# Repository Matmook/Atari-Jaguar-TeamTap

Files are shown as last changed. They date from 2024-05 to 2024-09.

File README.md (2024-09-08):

# Atari-Jaguar-TeamTap

This is an attempt to recreate the Atari Jaguar TeamTap schematic.

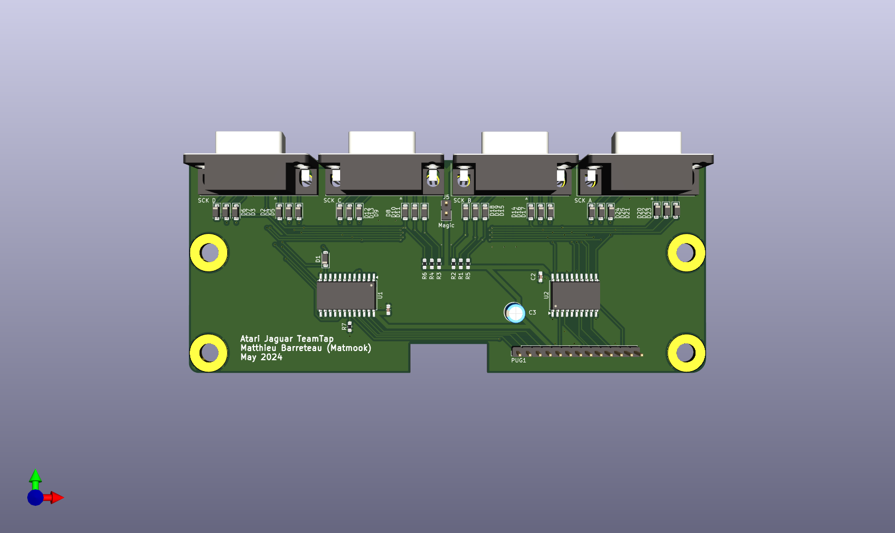
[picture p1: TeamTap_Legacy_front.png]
Front view

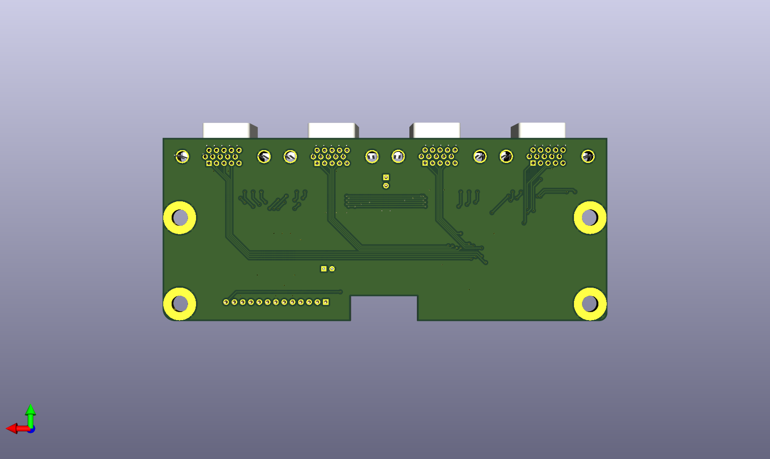
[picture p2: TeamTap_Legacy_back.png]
Back view


There is a catch on the original PCB: 
- the 5v from the Jaguar powers TeamTap's internal logic (74HC154 and 74HC244).
- pad's pin 7 is supposed to be used to power the pad's logic (74HC244).
- but all pads pin 7 are left floating in the TeamTam..
I guess that's some Atari magic => the pad's 74HC244 is fed by the other IOs, not VCC.
There is a "Magic" shunt on my pcb to test the pads behaviour when fed with 5v (as it should).

Matthieu Barreteau (Matmook) 2024

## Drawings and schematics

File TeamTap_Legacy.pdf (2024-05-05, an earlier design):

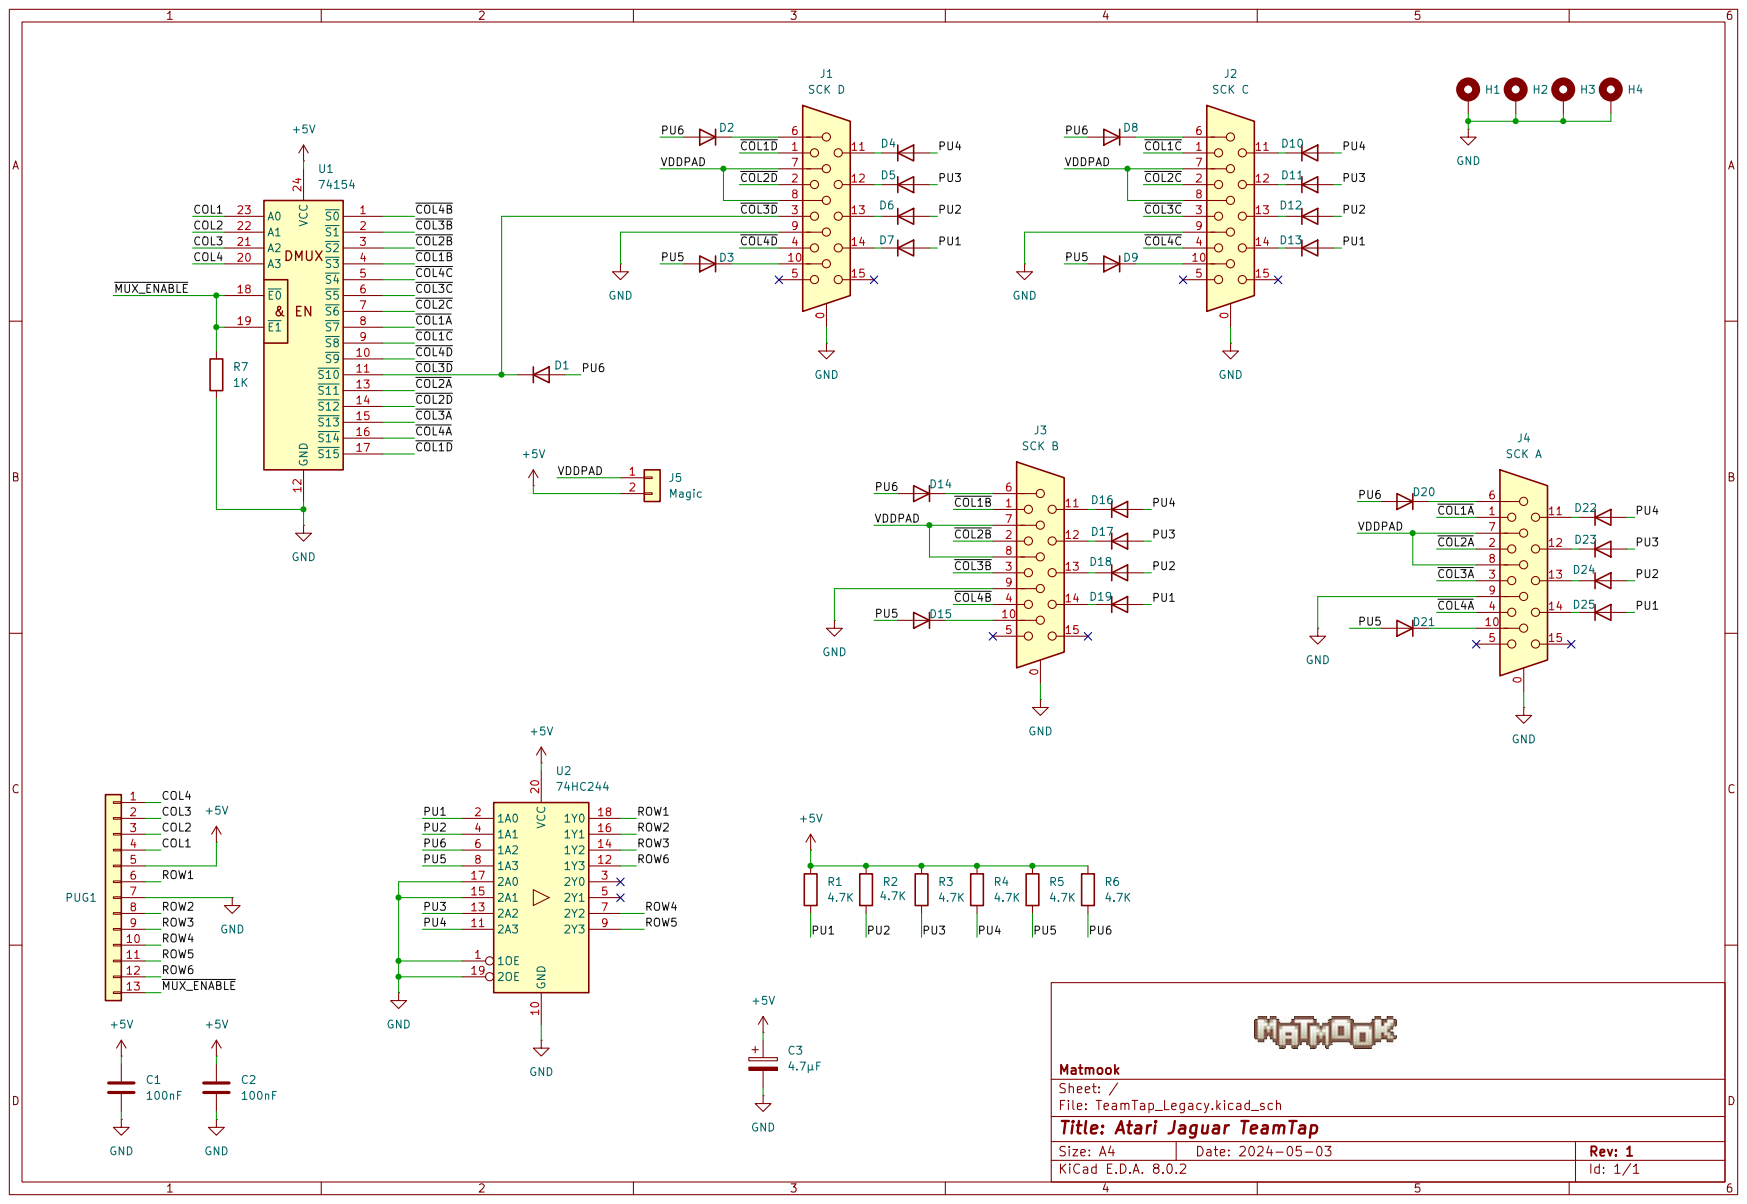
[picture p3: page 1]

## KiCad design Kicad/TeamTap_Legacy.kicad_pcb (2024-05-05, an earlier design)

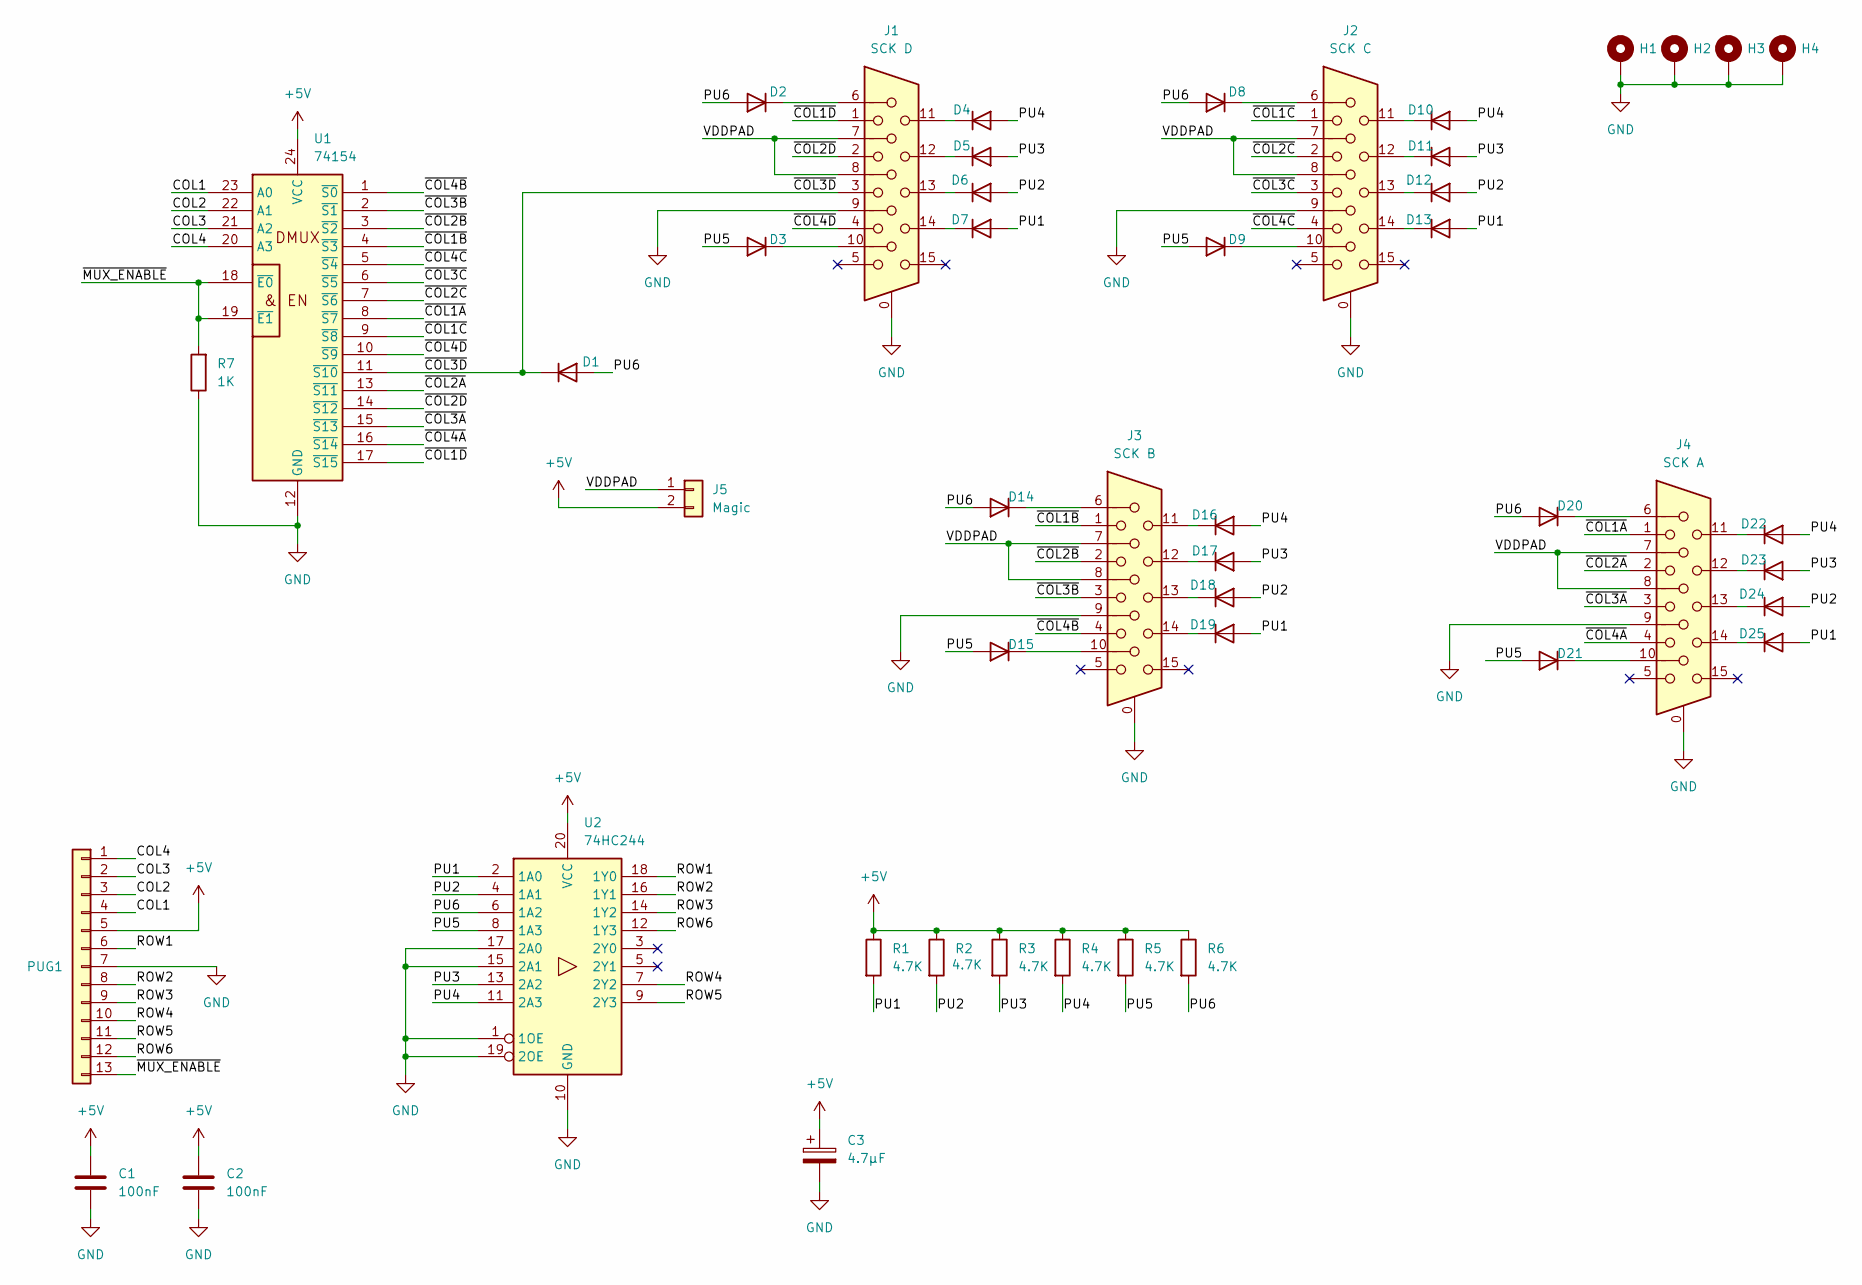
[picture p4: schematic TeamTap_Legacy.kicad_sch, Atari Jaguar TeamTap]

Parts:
C1, C2: 100nF; C_0603_1608Metric_Pad1.08x0.95mm_HandSolder
C3: 4.7µF; CP_Radial_D5.0mm_P2.50mm
D1, D2, D3, D4, D5, D6, D7, D8, D9, D10, D11, D12, D13, D14, D15, D16, D17, D18, D19, D20, D21, D22, D23, D24, D25: D; D_SOD-123
H1, H2, H3, H4: MountingHole_Pad; MountingHole_5mm_Pad_TopBottom
J1: SCK D; DSUB-15-HD_Male_Horizontal_P2.29x1.98mm_EdgePinOffset3.03mm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
J2: SCK C; DSUB-15-HD_Male_Horizontal_P2.29x1.98mm_EdgePinOffset3.03mm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
J3: SCK B; DSUB-15-HD_Male_Horizontal_P2.29x1.98mm_EdgePinOffset3.03mm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
J4: SCK A; DSUB-15-HD_Male_Horizontal_P2.29x1.98mm_EdgePinOffset3.03mm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
J5: Magic; PinHeader_1x02_P2.54mm_Vertical
PUG1: Conn_01x13; PinHeader_1x13_P2.54mm_Vertical
R1, R2, R3, R4, R5, R6: 4.7K; R_0603_1608Metric_Pad0.98x0.95mm_HandSolder
R7: 1K; R_0603_1608Metric_Pad0.98x0.95mm_HandSolder
U1: 74154; SOIC-24W_7.5x15.4mm_P1.27mm
U2: 74HC244; SOIC-20W_7.5x12.8mm_P1.27mm

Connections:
+5V: C1.1, C2.1, C3.1, J5.2, PUG1.5, R1.1, R2.1, R3.1, R4.1, R5.1, R6.1, U1.24 (VCC), U2.20 (VCC)
/COL1: PUG1.4, U1.23 (A0)
/COL2: PUG1.3, U1.22 (A1)
/COL3: PUG1.2, U1.21 (A2)
/COL4: PUG1.1, U1.20 (A3)
/PU1: D7.2 (A), D13.2 (A), D19.2 (A), D25.2 (A), R1.2, U2.2 (1A0)
/PU2: D6.2 (A), D12.2 (A), D18.2 (A), D24.2 (A), R2.2, U2.4 (1A1)
/PU3: D5.2 (A), D11.2 (A), D17.2 (A), D23.2 (A), R3.2, U2.13 (2A2)
/PU4: D4.2 (A), D10.2 (A), D16.2 (A), D22.2 (A), R4.2, U2.11 (2A3)
/PU5: D3.2 (A), D9.2 (A), D15.2 (A), D21.2 (A), R5.2, U2.8 (1A3)
/PU6: D1.2 (A), D2.2 (A), D8.2 (A), D14.2 (A), D20.2 (A), R6.2, U2.6 (1A2)
/ROW1: PUG1.6, U2.18 (1Y0)
/ROW2: PUG1.8, U2.16 (1Y1)
/ROW3: PUG1.9, U2.14 (1Y2)
/ROW4: PUG1.10, U2.7 (2Y2)
/ROW5: PUG1.11, U2.9 (2Y3)
/ROW6: PUG1.12, U2.12 (1Y3)
/VDDPAD: J1.7, J1.8, J2.7, J2.8, J3.7, J3.8, J4.7, J4.8, J5.1
/~COL1A: J4.1, U1.8 (~S7)
/~COL1B: J3.1, U1.4 (~S3)
/~COL1C: J2.1, U1.9 (~S8)
/~COL1D: J1.1, U1.17 (~S15)
/~COL2A: J4.2, U1.13 (~S11)
/~COL2B: J3.2, U1.3 (~S2)
/~COL2C: J2.2, U1.7 (~S6)
/~COL2D: J1.2, U1.14 (~S12)
/~COL3A: J4.3, U1.15 (~S13)
/~COL3B: J3.3, U1.2 (~S1)
/~COL3C: J2.3, U1.6 (~S5)
/~COL3D: D1.1 (K), J1.3, U1.11 (~S10)
/~COL4A: J4.4, U1.16 (~S14)
/~COL4B: J3.4, U1.1 (~S0)
/~COL4C: J2.4, U1.5 (~S4)
/~COL4D: J1.4, U1.10 (~S9)
/~MUX_ENABLE: PUG1.13, R7.2, U1.18 (~E0), U1.19 (~E1)
GND: C1.2, C2.2, C3.2, H1.1, H2.1, H3.1, H4.1, J1.0, J1.9, J2.0, J2.9, J3.0, J3.9, J4.0, J4.9, PUG1.7, R7.1, U1.12 (GND), U2.1 (1OE), U2.10 (GND), U2.15 (2A1), U2.17 (2A0), U2.19 (2OE)
unnamed: D2.1 (K), J1.6
unnamed: D3.1 (K), J1.10
unnamed: D4.1 (K), J1.11
unnamed: D5.1 (K), J1.12
unnamed: D6.1 (K), J1.13
unnamed: D7.1 (K), J1.14
unnamed: D8.1 (K), J2.6
unnamed: D9.1 (K), J2.10
unnamed: D10.1 (K), J2.11
unnamed: D11.1 (K), J2.12
unnamed: D12.1 (K), J2.13
unnamed: D13.1 (K), J2.14
unnamed: D14.1 (K), J3.6
unnamed: D15.1 (K), J3.10
unnamed: D16.1 (K), J3.11
unnamed: D17.1 (K), J3.12
unnamed: D18.1 (K), J3.13
unnamed: D19.1 (K), J3.14
unnamed: D20.1 (K), J4.6
unnamed: D21.1 (K), J4.10
unnamed: D22.1 (K), J4.11
unnamed: D23.1 (K), J4.12
unnamed: D24.1 (K), J4.13
unnamed: D25.1 (K), J4.14

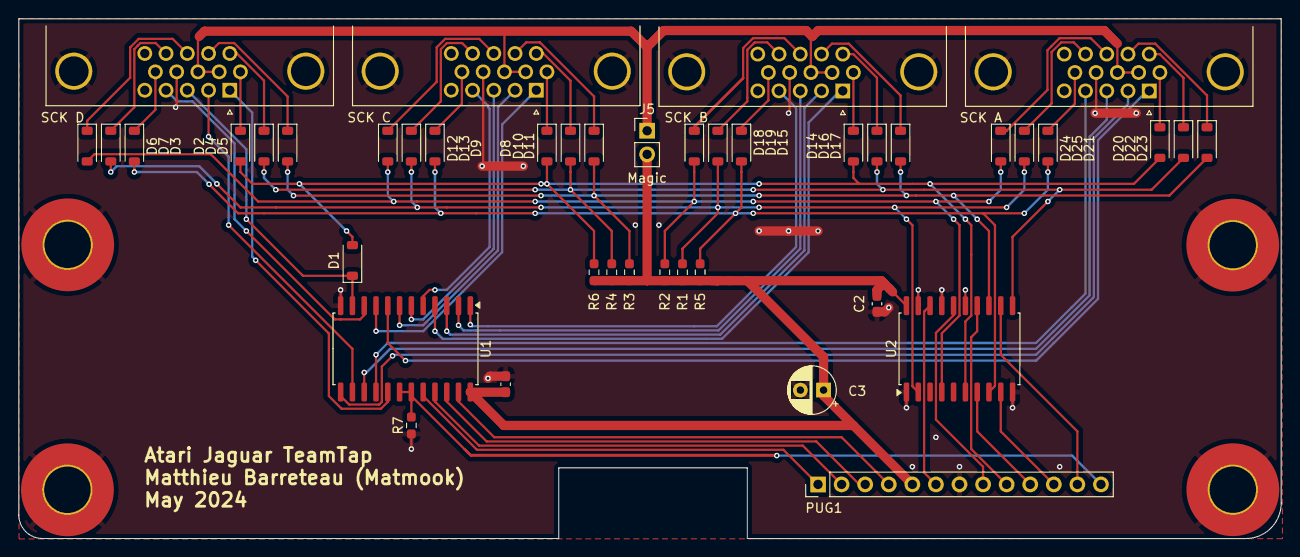
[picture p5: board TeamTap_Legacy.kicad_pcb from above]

Board: 2 copper layers, 136.0 x 56.0 mm, 47 parts (0 on the bottom side), 60 nets.
